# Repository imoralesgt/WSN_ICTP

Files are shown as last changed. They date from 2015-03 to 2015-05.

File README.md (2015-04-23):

# WSN_ICTP
WSN Implemented from scratch. Revision 2 - working at ICTP

===========================================================

ToDo:
+ Node side
  - ```(DONE) Battery measurement and monitoring for each node ```
  - ```(DONE) Low-battery alerting for each node on Exosite```
  - Improve battery lifetime
    * ```(DONE) [Nothing to fix :'(] May be turning sensors off should be the best solution (radios are working great)```
    * Firmware fine-tuning and optimization
  - ```(DONE) Design a PCB to allocate MSP430, radio and sensors (without Launchpad)```
  - ```(DONE) Send PCB to a manufacturing service (Seeed, iTead, etc.)```
  - 3D-printable case

+ Gateway side
  - ```(DONE) Fix date stamping bug```
  - ```(DONE) Fix bug: data was being sent with previously stored value after a node went offline```
  - ```(DONE) ThingSpeak server @ Raspberry PI [http://angryelectron.com/how-to-install-a-thingspeak-server/]```
  - ```(DONE) Change baudrate between RPi and MSP430 from 9.6kbps to 115.2kbps```
  - ```(DONE) Read sampling period from external text file```
  - ```(DONE) Implement a customized Thingspeak server @ RaspberryPI for local data visualization and exporting capabilities```
  - ```(DONE) Implement a reliable Python class to drive local Thingspeak's client side```
  - ```(DONE) Remove CIK from SC and read it from a text file```
  - ```(DONE) Design a PCB (as a Raspberry PI Hat. Using only MSP430 uC, without any Launchpad)```
  - ```(DONE) Send PCB to a manufacturing service (Seeed, iTead, etc.)```
  - 3D-printable case
  - Highstock graphs for a nice data visualization (http://www.highcharts.com/products/highstock)

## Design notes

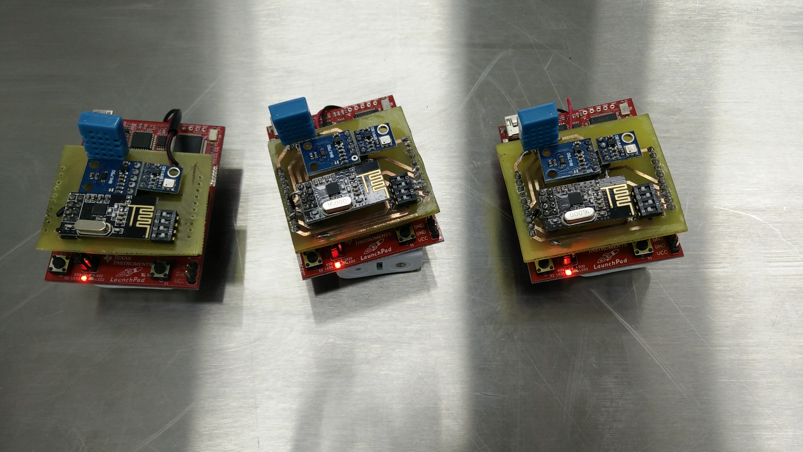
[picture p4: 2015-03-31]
IMG-20141124-WA0000.jpg

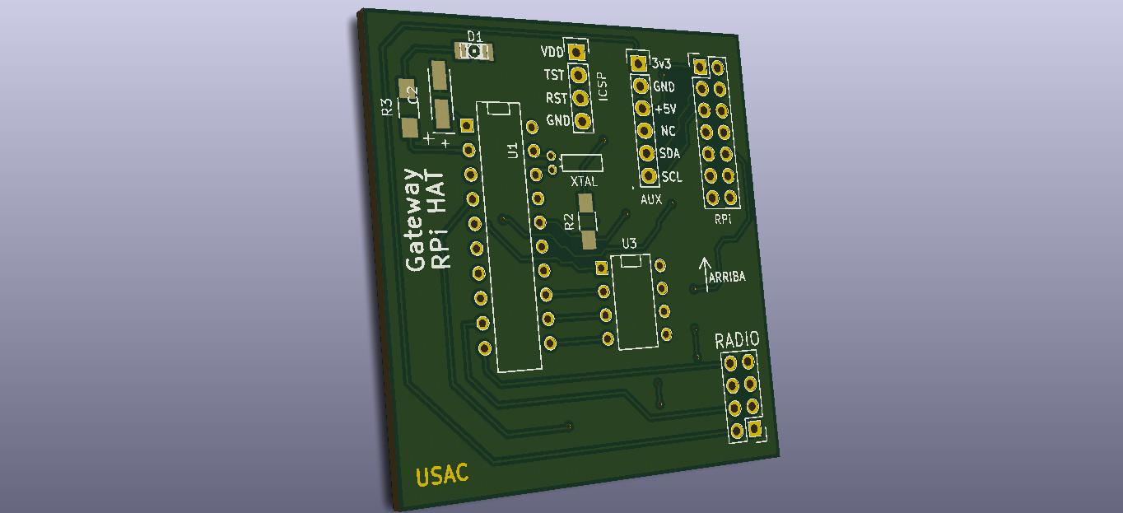
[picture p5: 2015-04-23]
KiCAD/Gateway/preview/front01.jpg

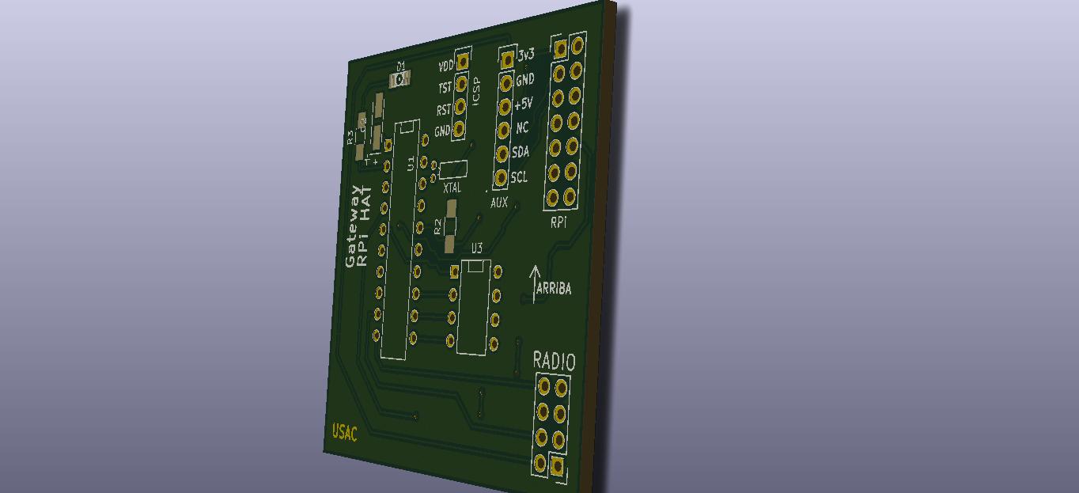
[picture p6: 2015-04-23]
KiCAD/Gateway/preview/front02.jpg

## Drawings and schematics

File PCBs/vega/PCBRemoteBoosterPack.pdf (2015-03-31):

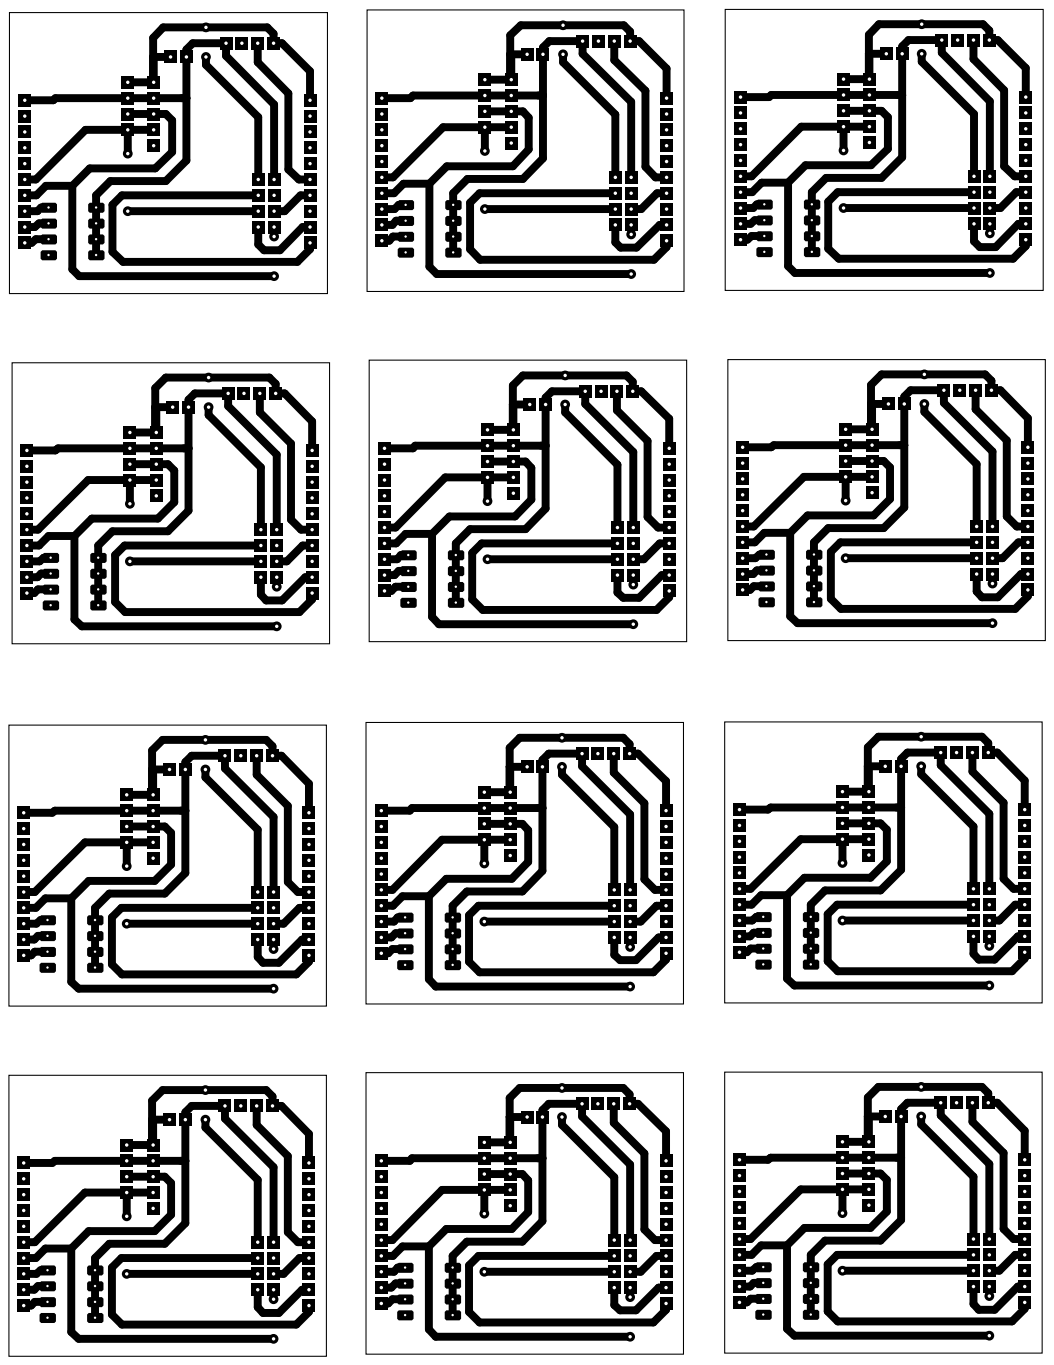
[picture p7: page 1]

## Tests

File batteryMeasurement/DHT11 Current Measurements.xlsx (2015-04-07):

Shunt Resistor | 11 | Ohms
Battery Voltate | 3.00 | V
Acquisition (peak) |  |  | Energy consumed during power-on state
Vmax during | 0.196 | V | Acquisition | 2.245090909e-06 | A*s
Peak period | 4.2e-05 | s | Sampling | 0.01141527273 | A*s
Vmin during | 0.014 | V | Total | 0.01141751782 | A*s
 |  |  | Total (A*h) | 3.171532727e-06 | A*h
Sampling window
Vmean | 0.192 | V
Period | 0.218 | s | Assuming continuous operation, 2xAA (2 A*h) batteries
 |  |  | may keep this sensor running (assuming batteries will be
Idle |  |  | discharged 'till their 30%)
Vmean | 0.00096 | V |  | 441426.9 | hours
Period | Based on optimization |  |  | 18392.8 | days
 |  |  |  | 613.1 | months
 | This sensor is not significantly affecting low-power capabilities at all!
 | Will not be disconnected dinamically.

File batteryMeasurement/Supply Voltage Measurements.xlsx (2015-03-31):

Theoretical values |  | Experimental data
Theoretical ADC Value | Voltage (mV) | Experimental ADC Value | Difference | Error
809 | 2372.434018 | 820 | 11 | 1.36%
826 | 2422.28739 | 836 | 10 | 1.21%
852 | 2498.533724 | 863 | 11 | 1.29%
874 | 2563.049853 | 884 | 10 | 1.14%
876 | 2568.914956 | 887 | 11 | 1.26%
925 | 2712.609971 | 936 | 11 | 1.19%
941 | 2759.530792 | 951 | 10 | 1.06%
947 | 2777.1261 | 957 | 10 | 1.06%
955 | 2800.58651 | 965 | 10 | 1.05%
976 | 2862.170088 | 989 | 13 | 1.33%
978 | 2868.035191 | 991 | 13 | 1.33%
980 | 2873.900293 | 990 | 10 | 1.02%
991 | 2906.158358 | 1002 | 11 | 1.11%
1012 | 2967.741935 | 1022 | 10 | 0.99%
 |  | Mean | 10.79 |  | To calculate Vdd from "n" value (read from ADC) use the following equation
 |  | Std Dev | 1.05
 |  | R^2 | 0.9998749962 |  |  | Vdd = 3*n/1023 | This one is derived parting from the fact that
 |  |  |  |  |  |  |  | Vin = Vdd/2
README!!! (take a look to the next lines right underneath)
 |  |  |  |  |  |  |  | Vref = 1.5V
Used MSP430's internal 1.5V reference to measure supply voltage
In order to do it, just read Analog Channel 11. This channel provides |  |  |  |  |  |  |  | Vin is also equal to
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

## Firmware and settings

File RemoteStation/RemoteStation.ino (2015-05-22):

#include <Enrf24.h>    //NRF24L01 Radio
#include <string.h>    //Strcmp and other string functions
#include <SPI.h>       //Hardware SPI
#include <Wire.h>      //Hardware I2C
#include <BMP085_t.h>  //Pressure and Temperature Sensor
#include <BH1750.h>    //Light sensor
#include <dht11.h>     //Humidity sensor
#include <RTCplus.h>   //Real time clock

#define SENSOR_COUNT 5

//const byte IRQ_PIN      = P2_2; //NRF24L01+ IRQ Pin
const byte CS_PIN      = P2_2; //NRF24L01+ CS Pin
const byte CE_PIN       = P2_0; //NRF24L01+ CE Pin
//const byte CS_PIN       = P2_1; //NRF24L01+ CS Pin
const byte IRQ_PIN       = P2_1; //NRF24L01+ IRQ Pin
const byte HUM_PIN      = P1_4; //DHT11 Data Pin
const byte LED1         = P1_0; //RED LED Pin
const byte ADDR_PINS[3] = {P2_3, P2_4, P2_5};

//const uint16_t RADIO_SPEED = 250000;
const uint16_t RADIO_SPEED = 1000000;

Enrf24 radio(CE_PIN, CS_PIN, IRQ_PIN);  // P2.0=CE, P2.1=CSN, P2.2=IRQ
BMP085<0> PSensor;
BH1750 lightMeter;
dht11 humSensor;
RealTimeClock rtc;

uint8_t rxaddr[] = { 0xDE, 0xAD, 0xBE, 0xEF, 0x01 };
const uint8_t txaddr[] = { 0xDE, 0xAD, 0xBE, 0xEF, 0x00 };
unsigned int TIME_OUT = 10; //Timeout before enabling RX radio
unsigned int now, start;
int32_t sensorData[SENSOR_COUNT]; //Temp, Pres, Lux, Hum
char firstTime;


const char *str_on = "ON";
const char *str_off = "OFF";

const char *STR_RQST_DATA = "DATA";
const char *STR_SET_TIMEOUT = "TIMEOUT";


//Prototypes
void dump_radio_status_to_serialport(uint8_t);
void wakeUp();
void dco1MHz();
void dco16MHz();
byte validateTimeOut();
unsigned int timeMinutes();
void radioInit();
void sensorsInit();
void enableRx();
void setLocalAddress(void);
void startupLedBlink(void);

void setup() {
  
  byte j;
  
  for(j=0; j<3; j++){
    pinMode(ADDR_PINS[j], INPUT_PULLUP);
  }
  
  setLocalAddress();
  
  pinMode(PUSH2, INPUT_PULLUP);
  delay(100);
  if(!digitalRead(PUSH2)){
    delay(25);
    if(!digitalRead(PUSH2)){
      TIME_OUT = 1;
    }
  }

  Serial.begin(9600);
 
  analogReference(INTERNAL1V5); //Set 1.5V internal reference as Vref+
                                //Used to measure baterry voltage
  radioInit();
  
  //dump_radio_status_to_serialport(radio.radioState());
  
  
  firstTime = 1;
  
  pinMode(P1_0, OUTPUT);
  digitalWrite(P1_0, LOW);
  
  
  
  startupLedBlink();

  enableRx();  // Start listening
  rtc.begin();
  now = timeMinutes();

}

void loop() {
  unsigned int tOut;
  char inbuf[33];
  
  dco16MHz();
  
  radioInit();
  enableRx(); //Start listening

  while (!radio.available(true))
    ;  
  if (radio.read(inbuf)) { //If some data was received
    delay(10);
    tOut = splitBufferToTimeOut(inbuf);
    //Serial.println(tOut);
    if (tOut > 0){ 
      TIME_OUT = tOut;
    //if (!strcmp(inbuf, STR_RQST_DATA)){
      //delay(10);
      //Serial.println(inbuf);
      //if (!strcmp(inbuf, STR_RQST_DATA)){ //If header is a DATA Request
         sensorsInit();
         digitalWrite(P1_0, LOW);
              
         humSensor.read(HUM_PIN);
         
         uint16_t hum = humSensor.humidity;
         //int temp = humSensor.temperature*10;
         int16_t temp = PSensor.temperature;
         //temp += PSensor.temperature;
         //temp /= 2;
         //int hum = humSensor.temperature;
         
         uint16_t lux = lightMeter.readLightLevel();
         if (firstTime){ //Fixed null first sampling bug
           lux = lightMeter.readLightLevel(); 
           lux = lightMeter.readLightLevel();
           firstTime = 0;
         }
         uint16_t bat = analogRead(11);
         bat = 60*bat/1023; 
         bat = 50*bat; //Converting ADC reading to voltage (mV)
         radioInit(); //Init radio as Tx
         radio.setTXaddress((void*)txaddr);
  
         //Temp, Pres, Lux, Hum       
         //sensorData[0] = PSensor.temperature;       //Celsius
         sensorData[0] = temp;       //Celsius
         sensorData[1] = (PSensor.pressure+50)/100; //hPa
         sensorData[2] = lux;                       //Luxes
         sensorData[3] = hum;                       //%HR
         sensorData[4] = bat;                       //Battery level
  
         
         /*
         Radio data will be sent as:
         MY_ID,TEMP,PRESS,LUX,HUM,BAT
         
         MY_ID <= UNIQUE NODE ID
         TEMP  <= TEMPERATURE*10 (FIXED POINT)
         PRESS <= ATM. PRESSURE (hPa)
         LUX   <= LIGHT METER MEASUREMENT (lux)
         HUM   <= RELATIVE HUMIDITY (%)
         BAT   <= BATTERY VOLTAGE (mV)
         */
         
         //long sum = rxaddr[4];
         int i;
         radio.print(rxaddr[4]); //Send my Address
         radio.print(",");
         digitalWrite(P1_0, HIGH);
         //radio.print(sensorData[0]/10); //Send temperature
         //radio.print(".");
         //radio.print(sensorData[0]%10); //Send one-digit decimal temperature
         for (i = 0; i < SENSOR_COUNT; i++){ //Send sensors' data
           //sum += sensorData[i];
           radio.print(sensorData[i]);
           radio.print(","); //Comma-separated values
         }
         digitalWrite(P1_0, LOW);
         //byte hash = (sum%256); //Simple hash used as checksum
         //radio.print(hash);
         //radio.print(",");
         radio.flush(); //Send the data that has been put in the radio's output buffer
     /*           
      //}else if(!strcmp(inbuf, STR_SET_TIMEOUT)){
      //}else{
        //radioInit(); //Init radio as Tx
        //radio.setTXaddress((void*)txaddr);
  
        //radioInit();
        //enableRx(); //Start listening
        while(strcmp(STR_SET_TIMEOUT, inbuf)){
          radio.read(inbuf); 
        }
        digitalWrite(P1_0, LOW);
        //while (!radio.available(true));
        if (radio.read(inbuf)){
          Serial.println(inbuf);
          TIME_OUT = atoi(inbuf);
          Serial.println(TIME_OUT, DEC);
          //radioInit(); //Init radio as Tx
          //radio.setTXaddress((void*)txaddr);
          //radio.print("OK");
          //radio.flush();
        }
      //} */
    }
  }
  
  
  
  now = timeMinutes();
  start = now;
  while(!validateTimeOut()){ //Periodically check: is it now time to wake up?
    now = timeMinutes();
    dco1MHz(); //Set DCO's speed to 1MHz
    __bis_status_register(LPM1_bits); //Low-Power Mode 1
  } 
}


void startupLedBlink(void){
  int i;
  for(i = 0; i < 6; i++){
    digitalWrite(P1_0, 1);
    delay(50);
    digitalWrite(P1_0, 0);
    delay(50);
  }
}

byte validateTimeOut(){ //Has already passed enough time to wake up?
   unsigned int localNow = now;
   if (start > localNow){ //Just in case an overflow exist
     localNow += 3600; 
   }
   if (localNow < (start + TIME_OUT)){
     return 0;
   }else{
     return 1;
   }
}

void setLocalAddress(void){
  byte addr;
         
  addr = (!digitalRead(ADDR_PINS[0]))   +
         (!digitalRead(ADDR_PINS[1]))*2 +
         (!digitalRead(ADDR_PINS[2]))*4;
  
  //addr = 1; //Just for debugging 
  rxaddr[4] = addr;
}

unsigned int timeMinutes(){
  return rtc.RTC_sec + rtc.RTC_min*60;
}

void wakeUp(){
  __bic_status_register(LPM0_bits); 
}

void dco1MHz(){
  BCSCTL1 = CALBC1_1MHZ;
  DCOCTL = CALDCO_1MHZ;
}

void dco16MHz(){
 BCSCTL1 = CALBC1_16MHZ;
 DCOCTL = CALDCO_16MHZ;  
}

interrupt(TIMER1_A0_VECTOR) Tic_Tac(void){
  rtc.Inc_sec();
  __bic_status_register(LPM1_bits);
};

void enableRx(){
  radio.setRXaddress(rxaddr);
  radio.enableRX();
  //digitalWrite(LED1, HIGH);
}

void radioInit(){
  SPI.begin();
  SPI.setDataMode(SPI_MODE0);
  SPI.setBitOrder(MSBFIRST);
  pinMode(IRQ_PIN, INPUT_PULLUP);
  radio.begin(RADIO_SPEED);
}

void sensorsInit(){
  Wire.begin();
  lightMeter.begin();
  PSensor.begin();
  PSensor.refresh();
  PSensor.calculate();
}

unsigned int splitBufferToTimeOut(char *buffer){
  char data[5][33];
  int i = 0;
  char *token, *basura;
  char *search = ",";
  token = strtok(buffer, search);
  while(token != NULL){
    strcpy(data[i], token);
    //Serial.println(data[i]); //Bulky code. Doesn't work without this debugging line :S
    Serial.print(NULL); //Bulky code. Doesn't work without this debugging line :S
    //strcpy(basura, data[i]); //Simply it doesn't work if I don't do this
    token = strtok(NULL, search);
    i++;
  }
  //Serial.println(data[1]);
  if(!strcmp(data[0], STR_RQST_DATA)){
    //Serial.println(data[1]);
    return atoi(data[1]);
  }else{
    return 0;
  }
}

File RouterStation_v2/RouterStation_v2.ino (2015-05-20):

#include <Enrf24.h>
#include <string.h>
#include <SPI.h>
#include <stdlib.h>
#include <RTCplus.h>

#define MAX_RETRIES 3  //3 max retransmission attempts
#define RTY_TIMEOUT 1  //1 second for timeout before attempting retransmission

const byte IRQ_PIN         = P2_2; //NRF24L01+ IRQ Pin
const byte CE_PIN          = P2_0; //NRF24L01+ CE Pin
const byte CS_PIN          = P2_1; //NRF24L01+ CS Pin
const byte RDY_PIN         = P1_4; //SD Card CS Pin
const byte STN_CNT_PINS[3] = {
  P2_3, P2_4, P2_5}; //Station Count PINs

Enrf24 radio(CE_PIN, CS_PIN, IRQ_PIN);
RealTimeClock rtc;

uint8_t txaddr[] = { 
  0xDE, 0xAD, 0xBE, 0xEF, 0x01 };
const uint8_t rxaddr[] = { 
  0xDE, 0xAD, 0xBE, 0xEF, 0x00 };
const uint16_t RADIO_SPEED = 1000000;

const char *str_on = "ON";
const char *str_off = "OFF";

const char *STR_RQST_DATA = "DATA";
const char *STR_SET_TIMEOUT = "TIMEOUT";

const char END_CHAR = ';';

const int DATA_LEN = 6;
const int BUFFER_SIZE = 33;

char inbuf[BUFFER_SIZE];

unsigned int TIME_OUT = 0;
byte STATIONS_COUNT = 0;
unsigned int sensorData[DATA_LEN];
byte failed=0; //Failed attempts to get data in current sampling

byte ledStatus = 0;


void dump_radio_status_to_serialport(uint8_t);

void radioInit(void){
  SPI.begin();
  SPI.setDataMode(SPI_MODE0);
  SPI.setBitOrder(MSBFIRST);
  radio.begin(RADIO_SPEED);  // Defaults 1Mbps, channel 0, max TX power
  radio.setTXaddress((void*)txaddr);
}

void countRemoteStations(void){
  byte cnt;

  cnt  = (!digitalRead(STN_CNT_PINS[0]))   +
    (!digitalRead(STN_CNT_PINS[1]))*2 +
    (!digitalRead(STN_CNT_PINS[2]))*4;

  //cnt = 1; //Just for debugging
  STATIONS_COUNT = cnt;
}


void reset(){
  WDTCTL = 0xFFFF; //Access violation to WDT causes software reset
}

void setTimeOut(void){
  char dataChar = '0';
  unsigned int tOt = 0;
  while (dataChar != END_CHAR){
    if(Serial.available() > 0){
      dataChar = Serial.read();
      if (dataChar != END_CHAR){
        tOt = tOt*10 + (dataChar - 48);
      }else{
        TIME_OUT = tOt;
      }
    }
  }
}

void startupLedBlink(void){
  int i;
  for(i = 0; i < 6; i++){
    digitalWrite(RED_LED, 1);
    delay(50);
    digitalWrite(RED_LED, 0);
    delay(50);
  }
}

void setup() {

  int j;

  pinMode(RDY_PIN, INPUT_PULLUP);
  while(digitalRead(RDY_PIN)){
    ;
  } //Wait until RPi has finished booting

  pinMode(RED_LED, OUTPUT);
  digitalWrite(RED_LED, 0);
  pinMode(PUSH2, INPUT_PULLUP);
  
  startupLedBlink();

  for(j = 0; j < 3; j++){
    pinMode(STN_CNT_PINS[j], INPUT_PULLUP);
  }

  Serial.begin(115200);
  
  setTimeOut();
  
  //TIME_OUT = getTimeOut(); //Read desired timeout from Gateway (RPi)
  //TIME_OUT = 10; //Read desired timeout from Gateway (RPi)
  
  countRemoteStations(); //set value on STATIONS_COUNT variable

  delay(100); //Initial setup delay

  digitalWrite(RED_LED, 1);

  radioInit();

  rtc.Set_Time(21,15,0);
  rtc.Set_Date(2014,8,30);
  rtc.begin();
  /*
  byte i;
   for(i = 1; i <= STATIONS_COUNT; i++){
   rqstAndSendTimeOut(i, inbuf);    
   }
   */
}


unsigned int deltaSeconds(int start, int now){ //Compute time gap between two samples
  if(start > now){
    now += 60;
  }
  return (now - start);
}

void splitBufferToData(char *buffer, unsigned int *data){
  int i = 0;
  char *token;
  char *search = ",";
  token = strtok(buffer, search);
  while(token != NULL){
    data[i] = atoi(token);
    token = strtok(NULL, search);
    i++;
  }
}


void dumpDataToSerial(char *data){
  //dumpTimeToSerial();
  Serial.print(data);
  Serial.print("\n");
}

void sendRadioDataRequest(byte destAddr){
  char tmpStr[33];
  char tmpTout[5];
  itoa(TIME_OUT, tmpTout, 10);
  txaddr[4] = destAddr;
  radio.setTXaddress(txaddr);
  strcpy(tmpStr, STR_RQST_DATA);
  strcat(tmpStr, ",");
  strcat(tmpStr, tmpTout);
  radio.print(tmpStr);
  radio.flush(); 
}

void sendTimeOutRequest(byte destAddr){
  txaddr[4] = destAddr;
  radio.setTXaddress(txaddr);
  radio.print(STR_SET_TIMEOUT);
  radio.flush();
}

void setRadioRxMode(void){
  radio.begin(RADIO_SPEED);
  radio.setRXaddress((void*)rxaddr);
  radio.enableRX(); //Start listening
}

unsigned int timeMinutes(){
  return rtc.RTC_sec + rtc.RTC_min*60;
}

byte validateSleepTime(unsigned int start, unsigned int now){ //Has already passed enough time to wake up?
  if(!digitalRead(PUSH2)){
    return 1;
  }
  unsigned int localNow = now;
  if (start > localNow){ //Just in case an overflow exist
    localNow += 3600; 
  }
  if (localNow < (start + TIME_OUT - failed*MAX_RETRIES*RTY_TIMEOUT)){
    return 0;
  }
  else{
    return 1;
  }
}

void dco1MHz(){
  BCSCTL1 = CALBC1_1MHZ;
  DCOCTL = CALDCO_1MHZ;
}

void dco16MHz(){
  BCSCTL1 = CALBC1_16MHZ;
  DCOCTL = CALDCO_16MHZ;  
}

void wdtSet(){
  //WDTCTL = WDTPW + WDTHOLD + WDTCNTCL; //Clear WDT+ Cnt
  //WDTCTL = WDTPW + WDTCNTCL + WDTSSEL; //WDT 32kHz source 1000ms
  WDTCTL = 0x5A0C;
}

void wdtReset(){
  //WDTCTL = 0x5A88;
  WDTCTL = WDTPW | WDTHOLD;
  //WDTCTL = WDTPW + WDTHOLD;
}

byte RQSTandReadData(byte ID, char *inbuf){
  int now, start, retries, dataValid;
  now = rtc.RTC_sec;
  start = now;
  retries = 0;

  dataValid = 0;

  while((retries < MAX_RETRIES) && (!dataValid)){
    start = rtc.RTC_sec;
    while(deltaSeconds(start,now) < RTY_TIMEOUT){
      digitalWrite(RED_LED, HIGH);
      now = rtc.RTC_sec;
      sendRadioDataRequest(ID);

      setRadioRxMode();
      digitalWrite(RED_LED, LOW);
      if(radio.available(true)){
        dataValid = 1;
        break;
      }
    }
    retries++;
  }
  digitalWrite(RED_LED, LOW);

  if(!dataValid){
    //dumpTimeToSerial();
    Serial.print("SIN RESPUESTA DE ESTACION #");
    Serial.println(ID, DEC);
    failed++;
  }

  if(radio.read(inbuf)) {
    dumpDataToSerial(inbuf);
    dataValid = 1;
    /*
    if(verifyHash(inbuf)){
     dataValid = 1;
     splitBufferToData(inbuf,sensorData);
     //Serial.print("\n");
     return 1;
     }
     else{
     Serial.println("  Error de Hash");
     dataValid = 0;
     return 0;
     }    
     */
  }

}


void rqstAndSendTimeOut(byte ID, char *inbuf){
  int now, start, retries, dataValid;
  now = rtc.RTC_sec;
  start = now;
  retries = 0;

  dataValid = 0;

  while((retries < MAX_RETRIES) && (!dataValid)){
    start = rtc.RTC_sec;
    while(deltaSeconds(start,now) < RTY_TIMEOUT){
      digitalWrite(RED_LED, HIGH);
      now = rtc.RTC_sec;
      sendTimeOutRequest(ID);

      setRadioRxMode();
      digitalWrite(RED_LED, LOW);
      if(radio.available(true)){
        dataValid = 1;
        break;
      }
    }
    retries++;
  }
  digitalWrite(RED_LED, LOW);

  if(!dataValid){
    Serial.print("SIN RESPUESTA DE ESTACION #");
    Serial.println(ID, DEC);
    failed++;
  }

  if(radio.read(inbuf)) {
    //dumpDataToSerial(inbuf);
    dataValid = 1;
  }

}
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

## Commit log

2015-03-31 Fork of original WSN implementation. Now at ICTP
    Battery measurement results added. 1V5 internal reference used along
    with analog channel 11 to read VDD/2.
    [20141110_074947.csv, 20141117_172020.xlsx, 20141119_150130.csv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]
2015-04-01 Fixed bug on date translation
    + Added 'May' to the MONTHS tuple
    + Added trailing zeros to months and days below 10
    [RPiLogger.py]
2015-04-07 DHT11 power consumption measurements
    Taken with oscilloscope. Conclusion: it's not necessary to turn it of,
    as it's not a significant power consumption source. Also, pre-heating
    must be enabled for at least 30 seconds before using it, so it's
    recommended to leave it on.
    [DHT11 Current Measurements.xlsx]
2015-04-07 Low-power optimization test
    Disabling DCO before going to sleep reduces power consumption by a
    factor of 2. Tested and successfully implemented on this test. Further
    test shall be done using main "RemoteStation" sketch.
2015-04-08 Exosite class - removed bug and added modularity
    - Removed bug: sending previously stored data after a sensor went down.
    - Added modularity: Now more variables can be added modifying the
    VARIABLES constant within exosite class
    [RPiLogger.py, RemoteStation.ino, exosite.py]
2015-04-08 Added support for battery measurement
    Now battery voltage (mV) is sent via radio. Succesffully tested at local
    stage. Exosite test not done yet.
2015-04-08 Added battery measurement and fixed Exosite's bug
    Now battery voltage (mV) can be seen at Exosite's Portal
2015-04-08 Added battery measurement at Gateway side
    Now it's sending battery voltage to Exosite. Successffully tested!
2015-04-08 Low-battery alerting has been added at Exosite
2015-04-08 Improved LED functionality on Node Stations
    Now LED can be permanently working to show radio's activity without
    draining considerable power from battery
2015-04-09 Not reading exosite.key file bug fixed
    [exosite.py]
2015-04-10 Changed GPIO pins to fit into RPi Hat PCB
2015-04-10 Gateway PCB done
    Gerbers are ready to send to PCB Fab
    [gatewayBoosterpack-B_Adhes.gbr, gatewayBoosterpack-B_Cu.gbr, gatewayBoosterpack-B_Mask.gbr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]
2015-04-14 Fixed even number bug
    Due to a (still) uknown reason, Nodes were not responding when timeout
    started with an even digit, no matter what size it was. Fixed by adding
    a BULKY Serial.println while splitting data into tokens. This is a
    power-hungry operation, but no other alternative was found :-1:
    [RemoteStation.ino]
2015-04-14 Real-time RF_TIMEOUT bug fixed!
    Now you can actually update RE_TIMEOUT on-the-fly by modifying
    "delay.set" file from any source
    [RPiLogger.py]
2015-04-16 Gateway PCB sent to SeeedStudio
    PCB sent to manufacturing service.
    [gatewayBoosterpack-B_Adhes.gbr, gatewayBoosterpack-B_Cu.gbl, gatewayBoosterpack-B_Cu.gbr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]
2015-04-16 Gateway's PCBs sent to SeeedStudio
2015-04-17 Gateway PCB gerber files updated
    [gatewayBoosterpack-B_Cu.gbl, gatewayBoosterpack-B_Mask.gbs, gatewayBoosterpack-B_SilkS.gbo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]
2015-04-21 Added PCB design for WSN Nodes
    Preliminar final design
    [NodesBoosterPack.kicad_pcb, NodesBoosterPack.sch]
2015-04-23 Preliminary commit - Nodes PCB
    [NodesBoosterPack-B_Cu.gbl, NodesBoosterPack-B_Mask.gbs, NodesBoosterPack-B_Paste.gbp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]
2015-04-23 Added gateway PCB preivew pictures
2015-04-23 Nodes PCBs sent to Seeed
2015-05-19 Fixed bug at RPiLogger
    Didn't read serial ttyAMA0 if sampling period didn't change. Now fixed!
    [RPiLogger.py, RouterStation_v2.ino]
2015-05-19 Revert "Fixed bug at RPiLogger"
    This reverts commit 4553928f26527573481daac29a80d1db7b1133b5.
    [RPiLogger.py, RouterStation_v2.ino]
2015-05-19 Revert "Revert "Fixed bug at RPiLogger""
    This reverts commit e40a0b3c6dd05553c6b0c58cf4ebb76a328f8f49.
    [RPiLogger.py, RouterStation_v2.ino]
2015-05-22 Null luminosity first sample bug fixed
    [RemoteStation.ino]
